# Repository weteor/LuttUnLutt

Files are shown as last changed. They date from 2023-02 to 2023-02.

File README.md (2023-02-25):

### Lütt un Lütt

3x5+2 key split orthogonal BLE keyboard

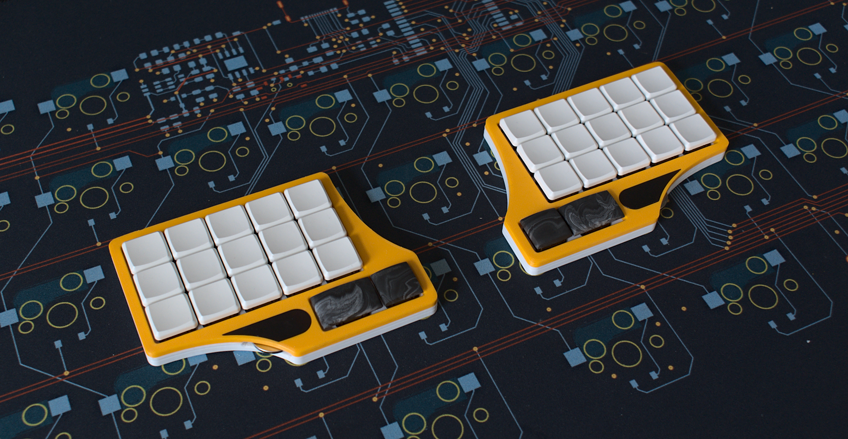
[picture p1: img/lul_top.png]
top


## Features

- full BLE, powered by coin cells (CR2032)
- choc v1 Hotswap sockets
- encoder
- case files are supplied (stl, dxf, as well as the freecad files)
- ZMK (with dongle support)
- completely open source, permissive license ([CERN-OHL-P](https://cern-ohl.web.cern.ch/home))

### what's left to do?
- fix small hole placement error in case
- fix battery opening in case
- fix cap placement on pcb right

### Want one?

All production files you need to build your own board can be found [here](./prod). they are certainly usable, but the case might need some scraping/cutting to properly fit the battery. I will fix that soon

The case is split in two parts connected by cylindrical 3x1.7mm magnets. The bottom case is open by design and ends at a bit under the hotswap sockets. It's meant to be used with self adhesive neopren sheets (2-3mm thick), which are cut to be the same size as the pcb and then glued on top of the underside of the pcb.

### the rest

Everything in this repository is free to use however you might see fit. If you want to support me and my projects, please consider linking back to this repository if you build/change/use anything.

If you would like to send me a tip, you could do it [here](https://ko-fi.com/weteor) (Please don't feel like you have to).

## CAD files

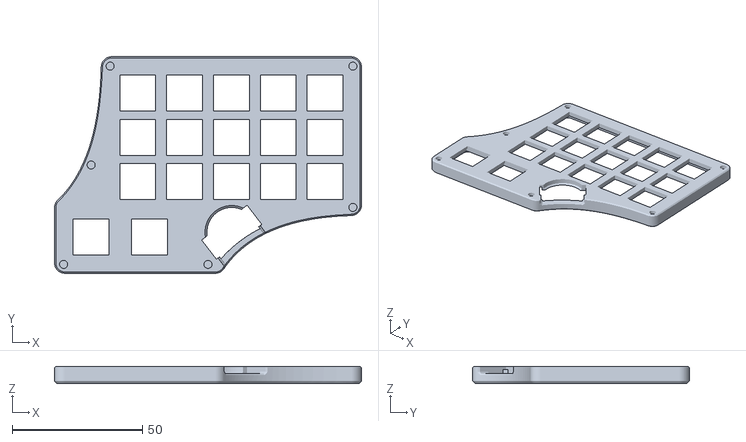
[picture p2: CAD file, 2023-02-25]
prod/case/lul_bottom_right.stl
118.0 x 83.2 x 6.65

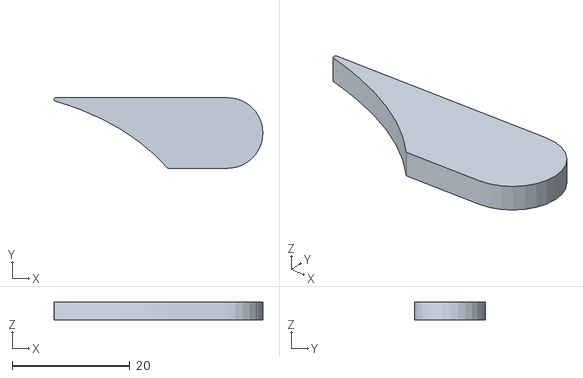
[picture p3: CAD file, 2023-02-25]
prod/case/window_left.stl
35.5 x 12.0 x 3.00

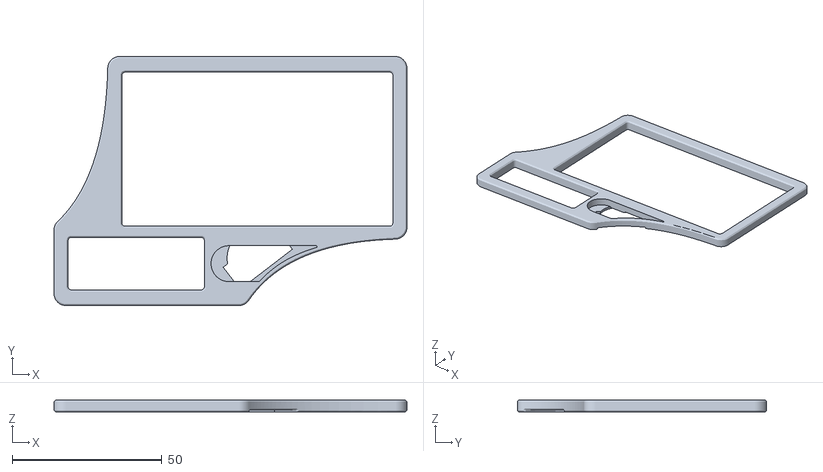
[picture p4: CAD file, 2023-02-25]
prod/case/lul_top_right.stl
118.0 x 83.2 x 4.00

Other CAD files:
prod/case/window_right.stl
prod/case/lul_bottom_left.stl
prod/case/lul_top_left.stl

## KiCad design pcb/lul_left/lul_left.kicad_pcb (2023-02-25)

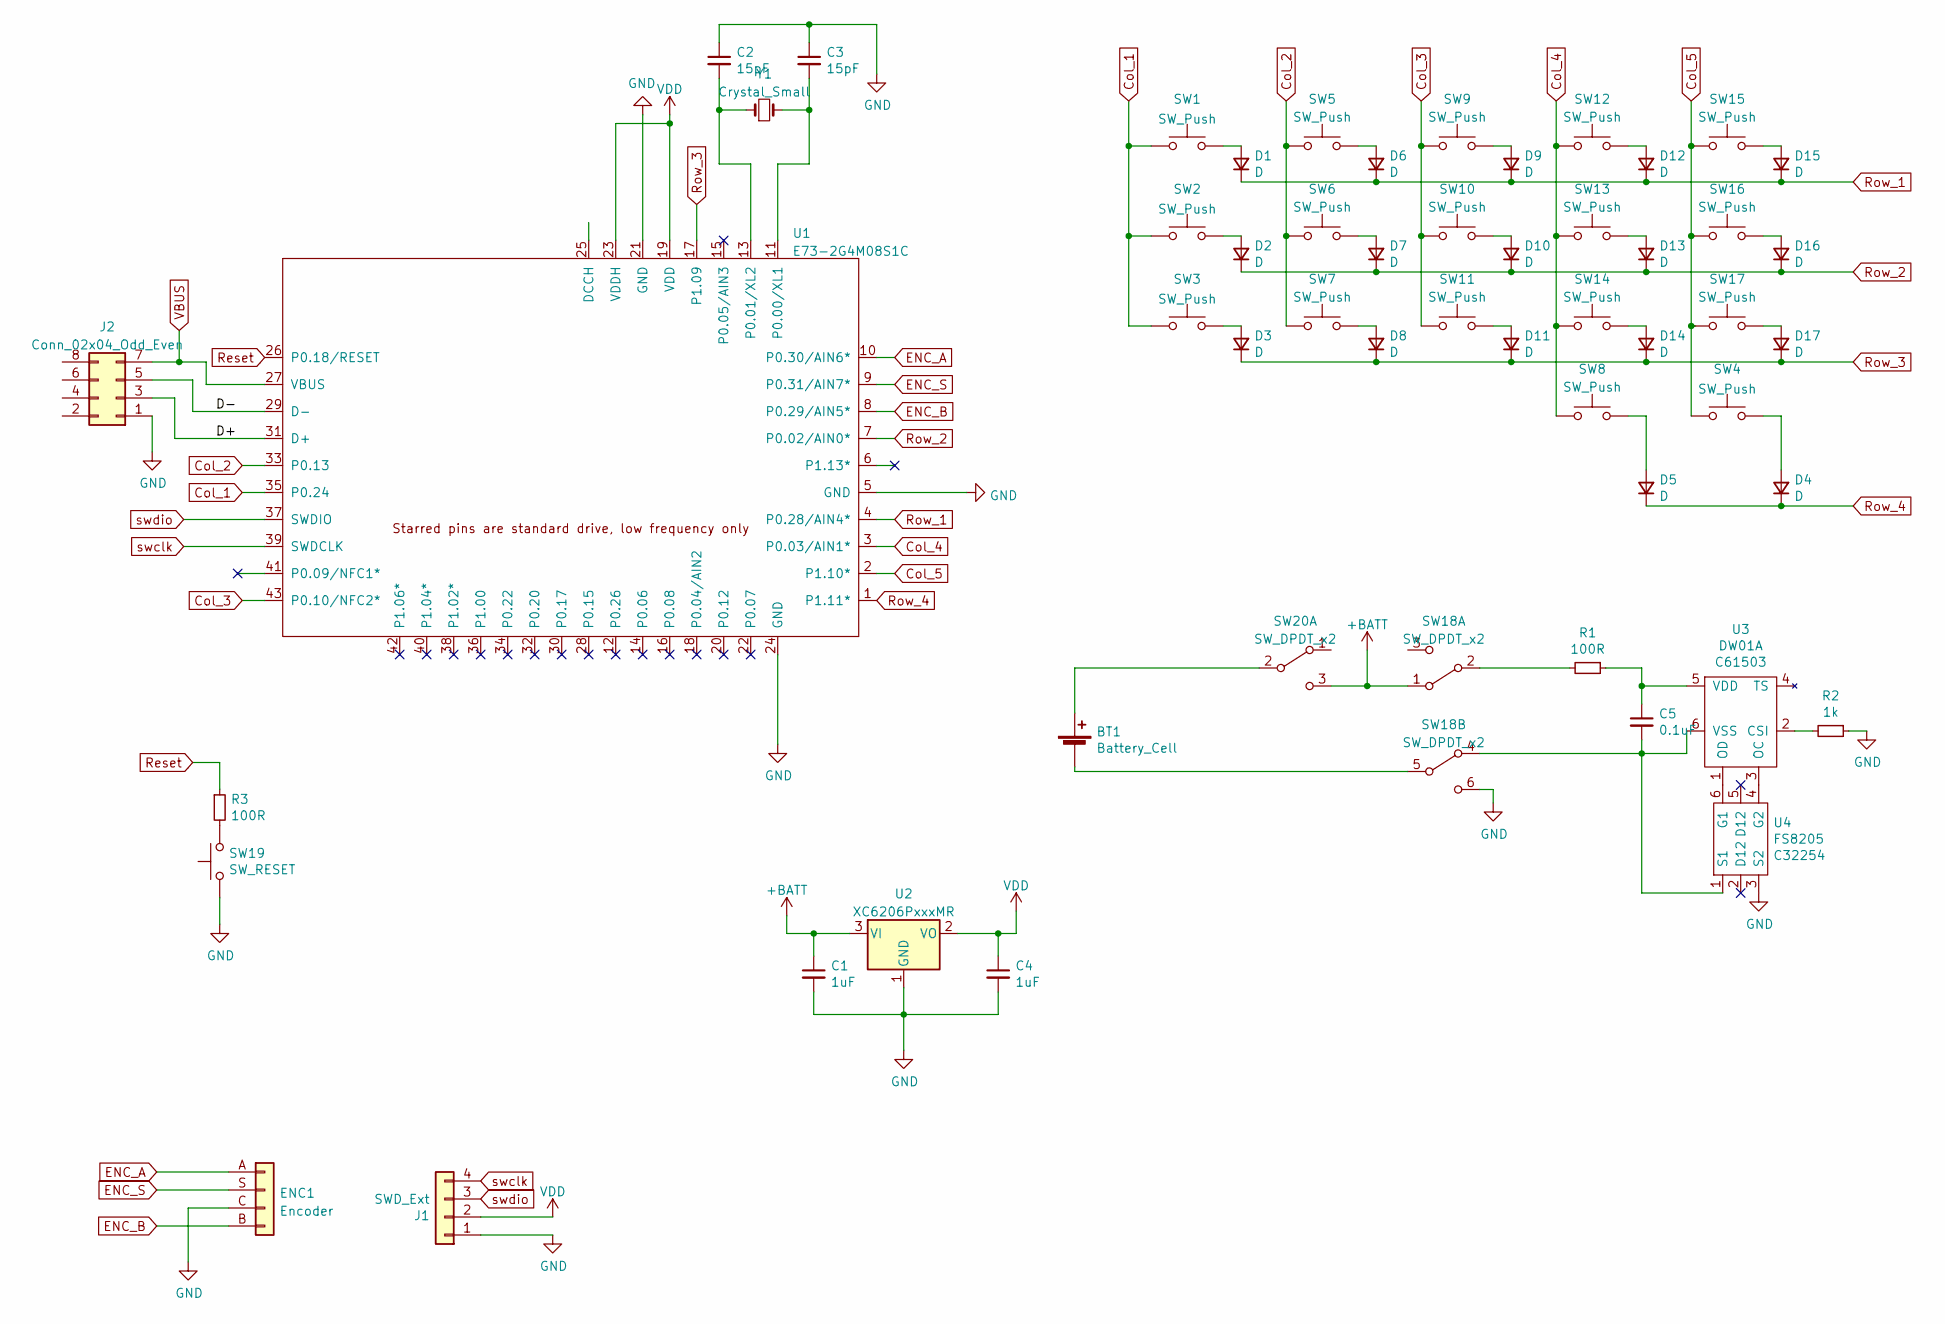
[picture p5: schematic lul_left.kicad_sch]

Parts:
BT1: Battery_Cell; Coin Cell 2032
C1, C4: 1uF; C_0603_1608Metric
C2, C3: 15pF; C_0603_1608Metric
C5: 0.1uF; C_0603_1608Metric
D1, D2, D3, D4, D5, D6, D7, D8, D9, D10, D11, D12, D13, D14, D15, D16, D17: D; D_SOD-123
ENC1: Encoder; Mitsumi_SIQ-02FVS3
J1: SWD_Ext; PinHeader_1x04_P2.54mm_Vertical
J2: Conn_02x04_Odd_Even; PinSocket_2x04_P1.27mm_Vertical
R1, R3: 100R; R_0603_1608Metric
R2: 1k; R_0603_1608Metric
SW1, SW2, SW3, SW4, SW5, SW6, SW7, SW9, SW10, SW11, SW12, SW13, SW14, SW15, SW16, SW17: SW_Push; ChocV1_V2_Hotswap_3d
SW8: SW_Push; ChocV1_V2_Hotswap_1.5u
SW18, SW20: SW_DPDT_x2; DPDT - C2837066
SW19: SW_RESET; Micro_Push_Button_3x6x2.5mm
U1: E73-2G4M08S1C; E73-2G4M08S1C_bottom
U2: XC6206PxxxMR; SOT-23
U3: DW01A; SOT-23-6; LCSC C61503
U4: FS8205; SOT-23-6; LCSC C32254
Y1: Crystal_Small; Crystal_SMD_3215-2Pin_3.2x1.5mm

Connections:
+BATT: C1.1, SW18.1 (A), SW20.3 (C), U2.3 (VI)
/D+: J2.3, U1.31 (D+)
/D-: J2.5, U1.29 (D-)
Col_1: SW1.1, SW2.1, SW3.1, U1.35 (P0.24)
Col_2: SW5.1, SW6.1, SW7.1, U1.33 (P0.13)
Col_3: SW9.1, SW10.1, SW11.1, U1.43 (P0.10/NFC2*)
Col_4: SW8.1, SW12.1, SW13.1, SW14.1, U1.3 (P0.03/AIN1*)
Col_5: SW4.1, SW15.1, SW16.1, SW17.1, U1.2 (P1.10*)
ENC_A: ENC1.A, U1.10 (P0.30/AIN6*)
ENC_B: ENC1.B, U1.8 (P0.29/AIN5*)
ENC_S: ENC1.S, U1.9 (P0.31/AIN7*)
GND: C1.2, C2.1, C3.1, C4.2, ENC1.C, J1.1, J2.1, R2.1, SW18.6 (C), SW19.1, U1.5 (GND), U1.21 (GND), U1.24 (GND), U2.1 (GND), U4.3 (S2)
unnamed: BT1.2 (-), SW18.5 (B)
unnamed: C2.2, U1.13 (P0.01/XL2), Y1.1
unnamed: C3.2, U1.11 (P0.00/XL1), Y1.2
unnamed: C5.1, R1.1, U3.5 (VDD)
unnamed: C5.2, SW18.4 (A), U3.6 (VSS), U4.1 (S1)
unnamed: D1.2 (A), SW1.2
unnamed: D2.2 (A), SW2.2
unnamed: D3.2 (A), SW3.2
unnamed: D4.2 (A), SW4.2
unnamed: D5.2 (A), SW8.2
unnamed: D6.2 (A), SW5.2
unnamed: D7.2 (A), SW6.2
unnamed: D8.2 (A), SW7.2
unnamed: D9.2 (A), SW9.2
unnamed: D10.2 (A), SW10.2
unnamed: D11.2 (A), SW11.2
unnamed: D12.2 (A), SW12.2
unnamed: D13.2 (A), SW13.2
unnamed: D14.2 (A), SW14.2
unnamed: D15.2 (A), SW15.2
unnamed: D16.2 (A), SW16.2
unnamed: D17.2 (A), SW17.2
unnamed: R1.2, SW18.2 (B)
unnamed: R2.2, U3.2 (CSI)
unnamed: R3.2, SW19.2
unnamed: BT1.1 (+), SW20.2 (B)
unnamed: U3.1 (OD), U4.6 (G1)
unnamed: U3.3 (OC), U4.4 (G2)
Reset: R3.1, U1.26 (P0.18/RESET)
Row_1: D1.1 (K), D6.1 (K), D9.1 (K), D12.1 (K), D15.1 (K), U1.4 (P0.28/AIN4*)
Row_2: D2.1 (K), D7.1 (K), D10.1 (K), D13.1 (K), D16.1 (K), U1.7 (P0.02/AIN0*)
Row_3: D3.1 (K), D8.1 (K), D11.1 (K), D14.1 (K), D17.1 (K), U1.17 (P1.09)
Row_4: D4.1 (K), D5.1 (K), U1.1 (P1.11*)
VBUS: J2.7, U1.27 (VBUS)
VDD: C4.1, J1.2, U1.19 (VDD), U1.23 (VDDH), U2.2 (VO)
swclk: J1.4, U1.39 (SWDCLK)
swdio: J1.3, U1.37 (SWDIO)

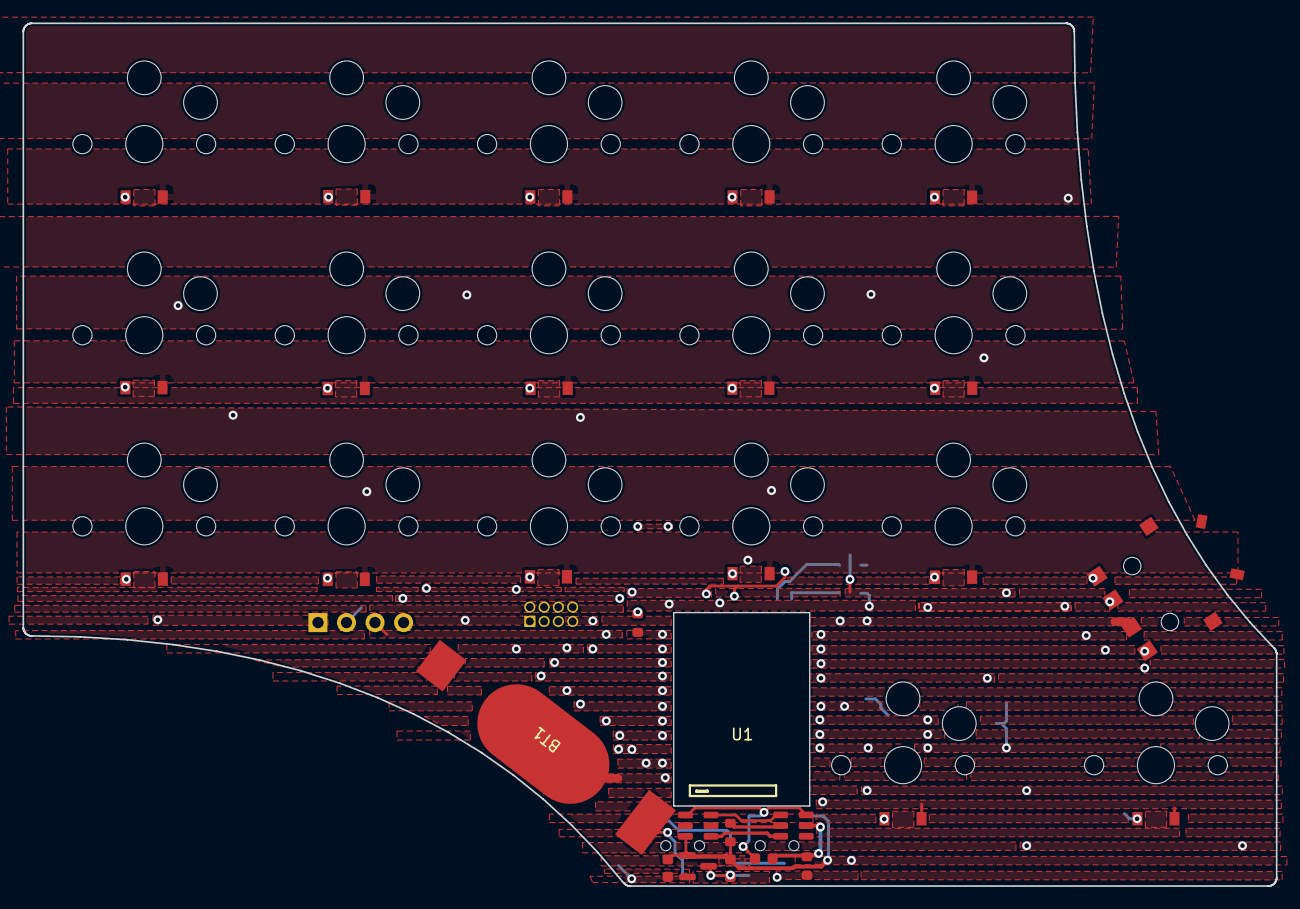
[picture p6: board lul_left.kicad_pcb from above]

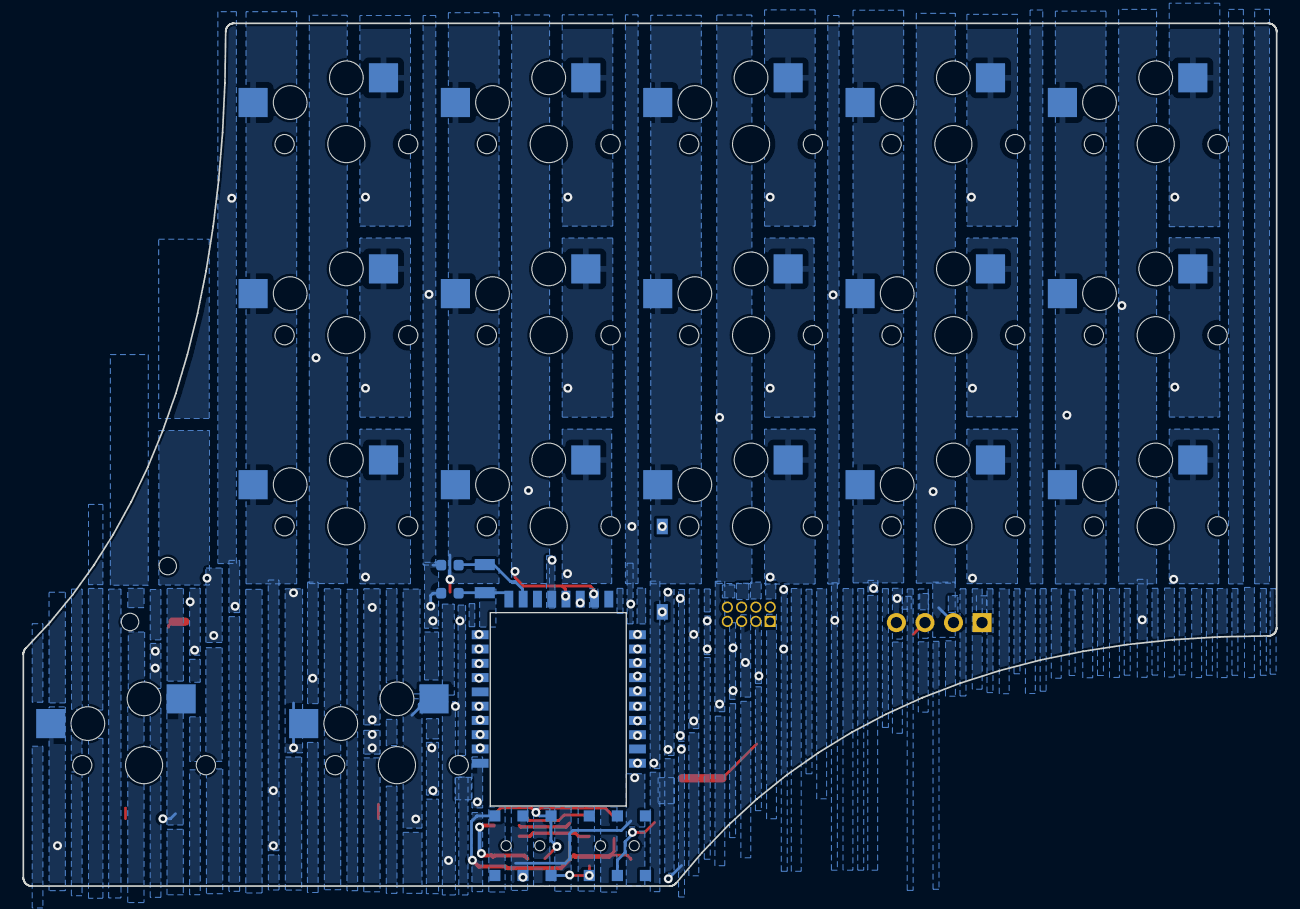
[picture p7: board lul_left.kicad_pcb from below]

Board: 2 copper layers, 111.5 x 76.8 mm, 54 parts (7 on the bottom side), 49 nets.

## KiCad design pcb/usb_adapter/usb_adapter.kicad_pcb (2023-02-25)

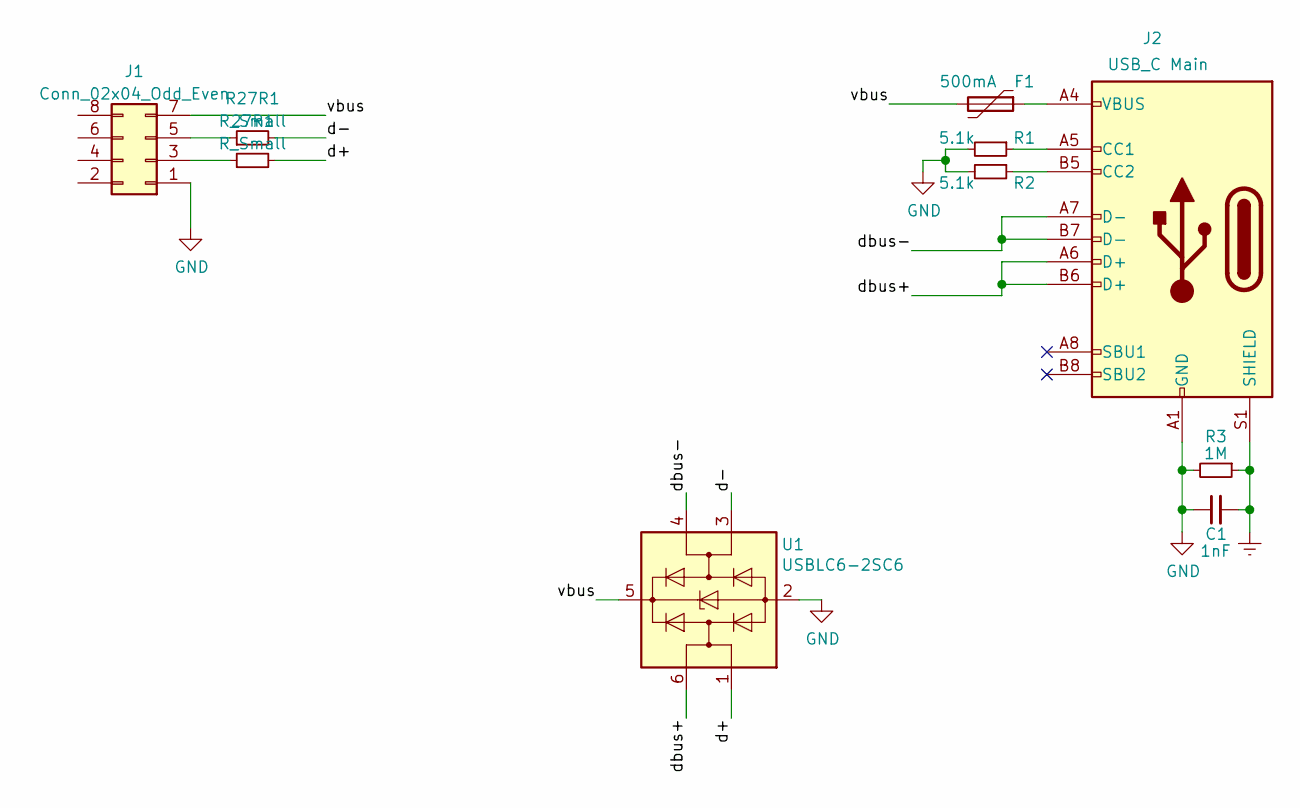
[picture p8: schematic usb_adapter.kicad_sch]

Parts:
27R1: R_Small; R_0805_2012Metric
C1: 1nF; C_0805_2012Metric
F1: 500mA; Fuse_1206_3216Metric
J1: Conn_02x04_Odd_Even; PinHeader_2x04_P1.27mm_Horizontal
J2: USB_C Main; USB-C-12-Pin-MidMount
R1, R2: 5.1k; R_0805_2012Metric_Pad1.20x1.40mm_HandSolder
R3: 1M; R_0805_2012Metric_Pad1.20x1.40mm_HandSolder
R27R1: R_Small; R_0805_2012Metric
U1: USBLC6-2SC6; SOT-23-6

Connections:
/d+: 27R1.2, U1.1 (I/O1)
/d-: R27R1.2, U1.3 (I/O2)
/dbus+: J2.A6 (D+), J2.B6 (D+), U1.6 (I/O1)
/dbus-: J2.A7 (D-), J2.B7 (D-), U1.4 (I/O2)
/vbus: F1.2, J1.7, U1.5 (VBUS)
Earth: C1.2, J2.S1 (SHIELD), R3.1
GND: C1.1, J1.1, J2.A1 (GND), J2.A12 (GND), J2.B1 (GND), J2.B12 (GND), R1.2, R2.2, R3.2, U1.2 (GND)
unnamed: 27R1.1, J1.3
unnamed: F1.1, J2.A4 (VBUS), J2.A9 (VBUS), J2.B4 (VBUS), J2.B9 (VBUS)
unnamed: J2.A5 (CC1), R1.1
unnamed: J2.B5 (CC2), R2.1
unnamed: J1.5, R27R1.1

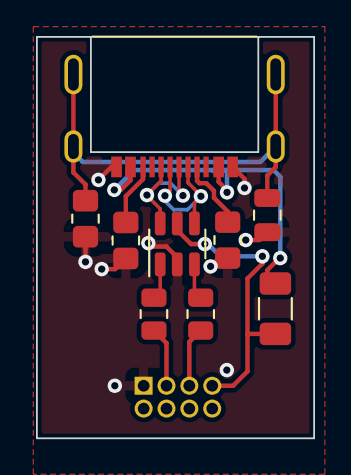
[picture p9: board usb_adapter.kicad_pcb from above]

Board: 2 copper layers, 15.4 x 22.3 mm, 10 parts (1 on the bottom side), 12 nets.

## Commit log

2023-02-25 add pcb cad
    [lul_left.kicad_pcb, lul_left.kicad_sch, lul_right.kicad_pcb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]
2023-02-25 add case cad
2023-02-25 add production files
    [lul_bottom_left.stl, lul_bottom_right.stl, lul_top_left.stl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]
